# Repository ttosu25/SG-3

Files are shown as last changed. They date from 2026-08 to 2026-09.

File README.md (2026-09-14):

# Overview

Strain gauges produce very small differential voltage signals that encode information about mechanical strain. Precise and accurate measurement requires careful analogue signal conditioning before digitisation, followed by digital signal processing to extract the desired measurement. This project explores the design of a complete measurement device, from sensor excitation and analogue front-end conditioning through to digital acquisition, processing, and display output.

# System Block Diagram
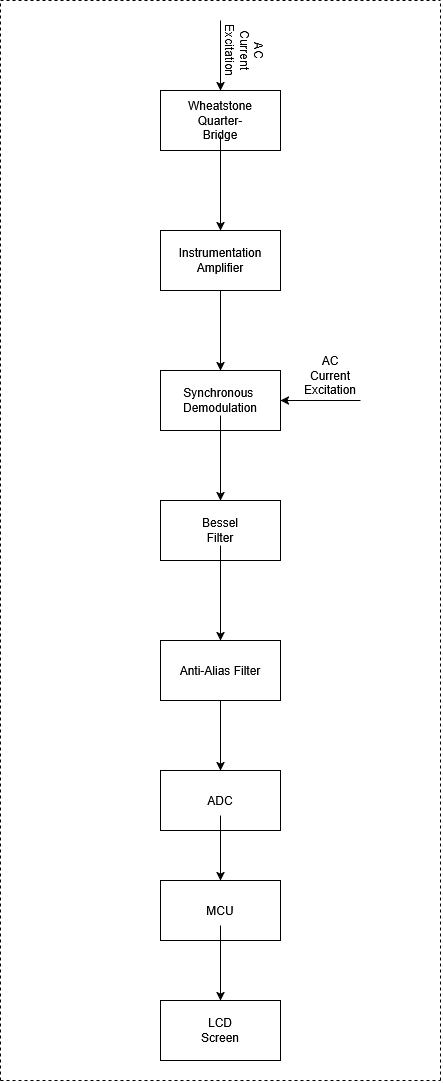
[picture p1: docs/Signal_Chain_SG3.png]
System Block Diagram


# Key Design Features

## AC Current Excitation
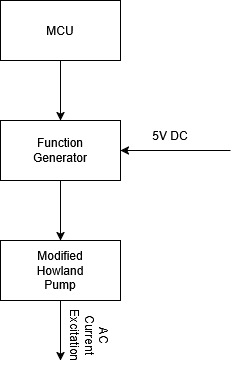
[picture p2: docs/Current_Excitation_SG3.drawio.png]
AC Current Excitation Block Diagram
  

Current-driven AC excitation: Current excitation improves the linearity between applied strain and differential bridge output. Using AC rather than DC excitation reduces measurement offset and drift, mitigates low frequency (1/f) noise, and suppresses parasitic thermoelectric effects.
  
## Bessel Filtering
The Bessel response was selected for its absence of overshoot and steeper amplitude roll-off compared with the Butterworth response. The filter also exhibits minimal passband variation and a simulated settling time of 7 ms, which is significantly shorter than the latency introduced by the sigma-delta ADC's digital filtering.

## Oversampled Sigma Delta ADC
Sigma-Delta converters contain integrated features such as digital filters that minimise the effect of extrinsic and intrinsic noise sources such as alias signal noise, 50/60hz power noise, RF noise pick up and clock jitter. The Oversampling nature of Sigma-Delta converts also distributes noise over a wider range of frequencies which reduces the effect of quantisation noise.

# Schematic
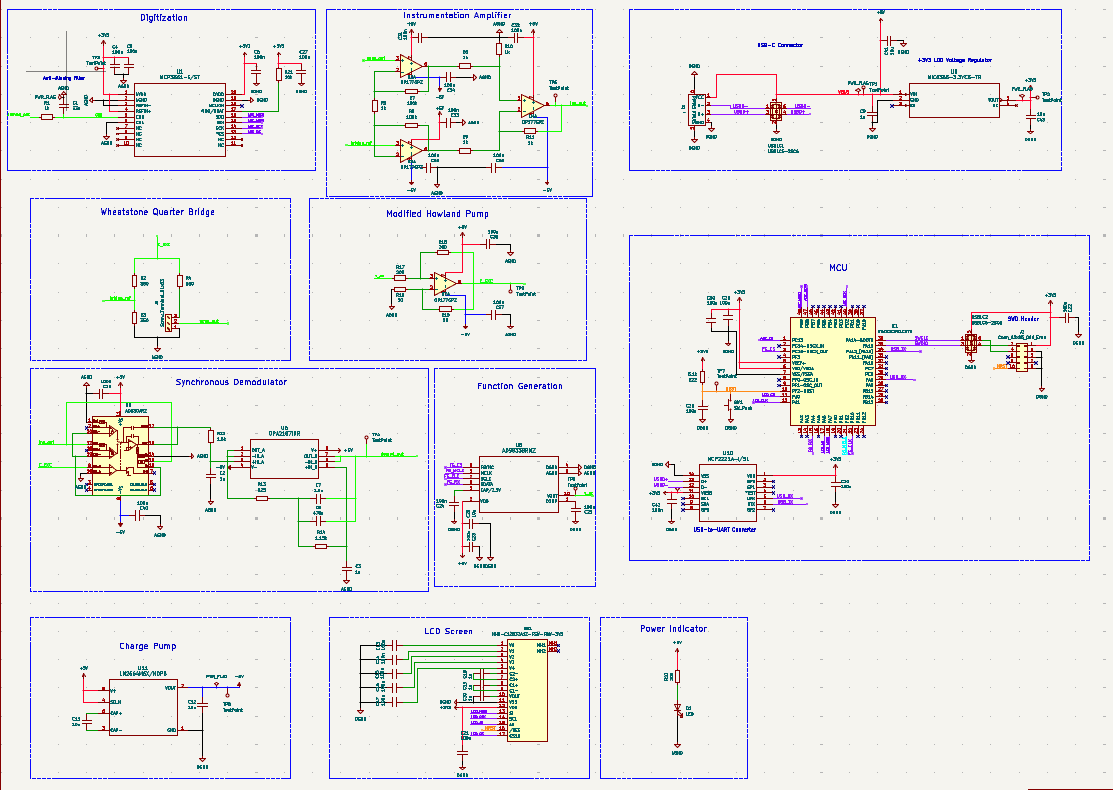
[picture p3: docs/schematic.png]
Hardware Schematic


# PCB Layout and Tracing
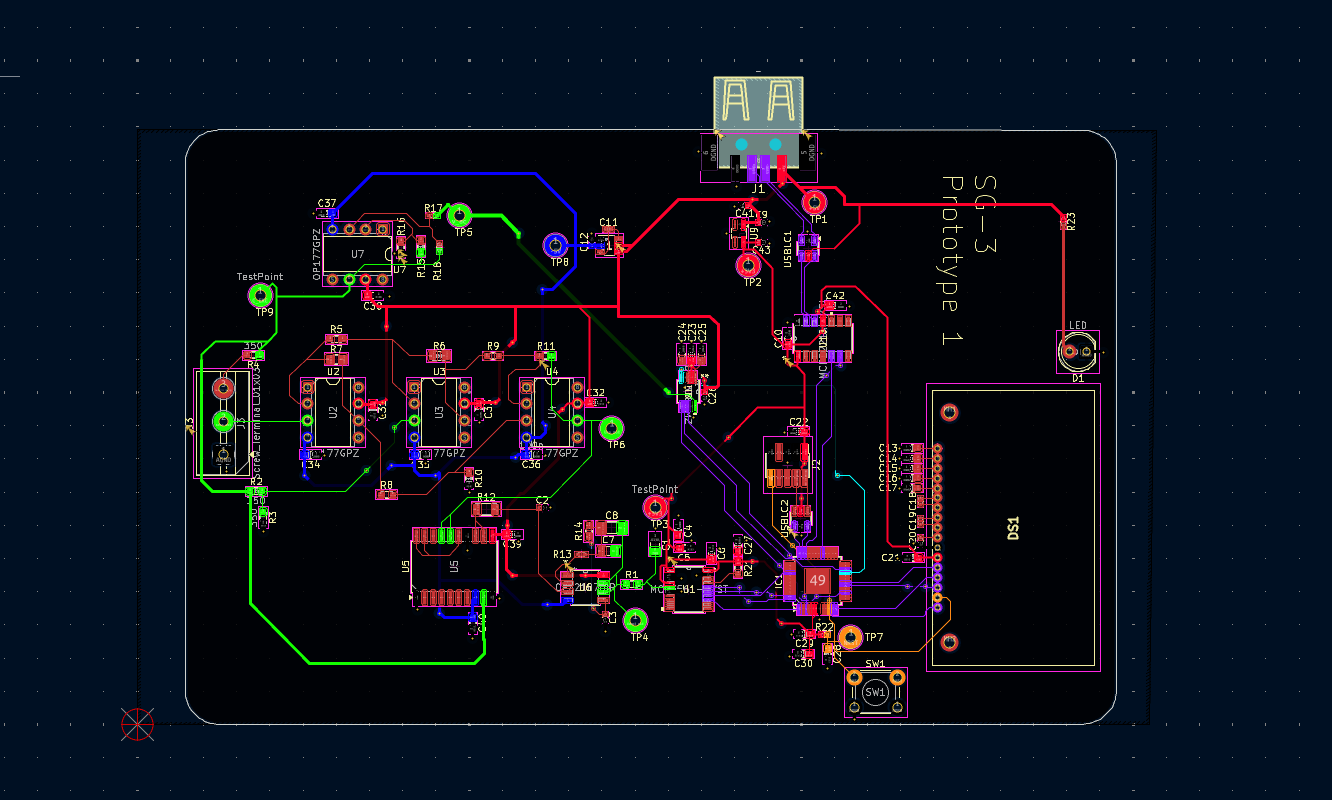
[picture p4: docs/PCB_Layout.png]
PCB Layout


# 3D model view
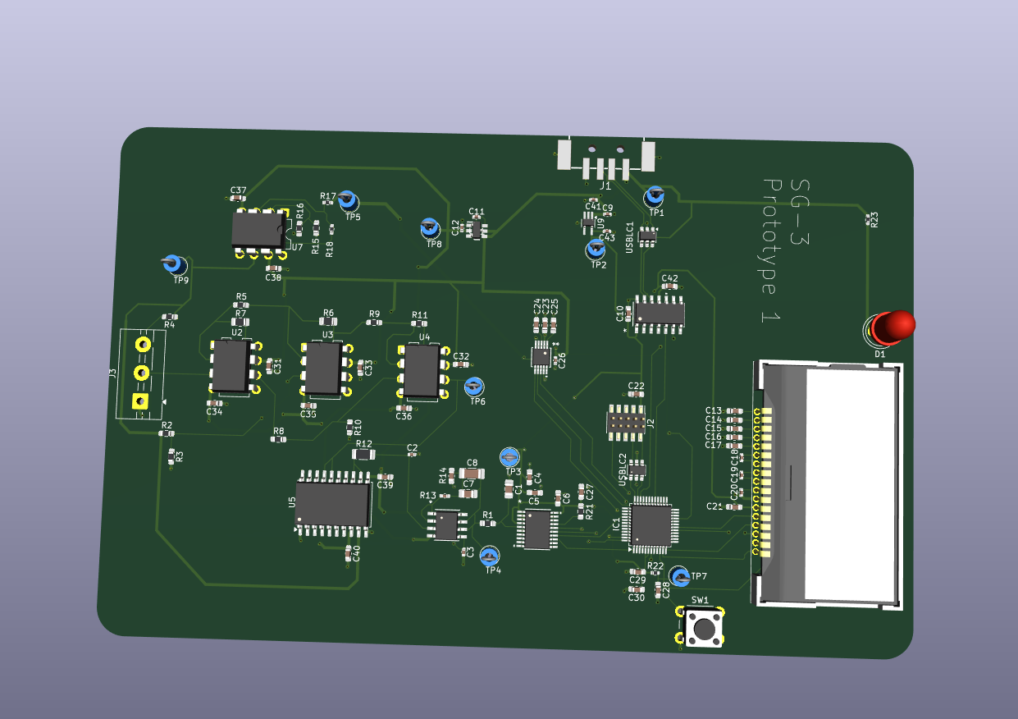
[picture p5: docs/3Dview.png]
3D model view


# Repository Structure

hardware/ — Contains the schematics, PCB layout files, Gerber files, MCU pin assignment, and hardware revisions.

tr/ — Contains technical research and supporting analysis, including datasheets, application notes, initial problem-space exploration, and SPICE simulations with FFT analysis.

docs/ — Contains the project specification, design documentation, and system diagrams.

firmware/ — Contains the programs running on the MCU for the embedded application.

Logbook entries not available.

# Status
Prototyping Stage, PCB fabricated.

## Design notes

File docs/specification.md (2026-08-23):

# Strain Gauge Measurement System (Load Sensing Node)

## 1. Project Overview

Design and implement a low-cost strain measurement system for monitoring mechanical strain on a loaded beam. The system will acquire strain data from a resistive strain gauge, condition the signal, and provide a digital output for logging and analysis.

The design should be suitable for laboratory testing and demonstrate correct analog signal conditioning principles.

## 2. Functional Requirements

The system shall:

Measure strain using a bonded resistive strain gauge
Convert strain into a usable electrical signal via a Wheatstone bridge
Condition the signal using analogue circuitry
Output a digital representation of strain for logging or display
Operate continuously under static or slowly varying loads

## 3. Sensor Requirements
Strain gauge nominal resistance: 350 Ω
Gauge factor: 2.0 ± 5%
Mounting: quarter-bridge configuration (unless justified otherwise in design)
Maximum strain range: 0 to 1200 µε
Assume linear elastic behaviour of the test specimen

## 4. Electrical Requirements

Minimum resolution target: ≤ 5 µε
Total system non-linearity: < 1% full scale

## 5. Data Conversion

ADC resolution: ≥ 12-bit
Sampling rate: ≥ 50 Hz

## 6. Mechanical Assumptions
Strain gauge is correctly bonded to a uniform metallic beam
Beam behaves within elastic region (Hooke’s law valid)
Temperature is approximately constant (20–25°C), but drift effects should be discussed

## 7. Environmental Constraints
Laboratory environment (non-industrial)
No significant vibration or EMI shielding provided
Cable lengths: up to 1 m between sensor and conditioning circuit

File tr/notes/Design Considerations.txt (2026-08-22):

The system seems to have a data flow structure as follows:

Force -> Foil Grid -> Piezoelectric signals -> Instrumentation Amplifier -> Signal Conditioning -> Digitization -> strain calculation/data logging system.

A reference voltage must be supplied to the instrumentation amplifier because strain gauges
can increase and decrease in resistance which produces a positive and negative differential bridge voltage. 

The reference voltage should be half the power supply voltage. A reference voltage at mid supply biases the output voltage of instrumentation amplifier to allow differential measurements in the positive and negative direction.

## References

Single-Supply Strain Gauge in a Bridge Configuration
Reference Design - TDI

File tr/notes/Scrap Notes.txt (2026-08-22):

## Overview

There are different implementations of a strain gauge using mechanical and optical methods. 
The type of strain-gauge to be designed and studied is the electrical resistance strain gauge.

These gauges are strongly bonded to the material being measured and they work on the principle that the electrical resistance of a conductive metal changes as it deforms. As the metal compresses and extends so does the gauge. By measuring the electrical signals generated due to these deformations, the object's change in length can be estimated and thus its strain on the surface.

## Construction

Consists of:
 - Conducting foil grid
 - Insulating plastic film
 - soldered tabs
 - alignment ends

The physical length of the grid is selected depending on the application. The shorter the length of the grid the more accurately the approximation of strain. However, a strain value averaged over a longer distance might be more meaningful for measuring strain of composite materials.

Different materials change resistance differently under the same unit strain. Materials that change resistance more for the same unit strain produce higher sensitivity strain gauges.

The sensitivity as a strain gauge is quantified by a parameter called the gauge factor K which is the ratio of the relative change in resistance to the strain.

Most general purpose strain gauges use foil grids made of constantan. It's K is moderate (2). Notably because of its performance with temperature. It's gauge factor varies very little between -50 to 150 degrees Celsius. Strain gauges tend to be used to measure small strains usually in the order of 1 to 1000 micro strain.

## Measurement

The principle circuit for the measurement of electrical signals in a strain gauge is a Wheatstone bridge. Its purpose is to determine the electric resistance of the strain gauge before and after a load has been applied.

### Basic Construction

- Four resistors arranged in a diamond shape
- A galvanometer splitting resistor network
- Voltage supply

## Temperature compensation

When materials experience temperature changes they expand and contract by a certain amount depending on their coefficient of thermal expansion (CTE) . The strain gauge material and the material being tested will have different CTEs so they will try to expand my different amounts.

This causes differential thermal expansion that gets added to strain different from what we are trying to measure.

### Compensation methods:

- active componesation
- self compensation

## Limitations

- Only measure normal strain in single direction.

## References
https://www.youtube.com/watch?v=CRa9djnZRu0

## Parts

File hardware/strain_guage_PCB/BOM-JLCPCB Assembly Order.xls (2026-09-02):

JLCPCB BOM Tool - BOM Matching
BOM name：BOM-JLCPCB Assembly Order.xlsx |  |  | Download Time：2026-09-02 18:14:43 |  |  |  | * Our matching results are updated in real-time, but stock and prices may change. If it's been over 24 hours, please re-match before placing your order.
PCB Assembled Qty：5 |  |  | Est. Total Price：240.3413
Your BOM |  |  |  | Matched Parts |  |  |  |  |  |  | Order Information
Designator | Comment | Footprint | JLCPCB Part # | Matches | Part # | Manufacturer | Footprint | Description | Category | Warning | JLCPCB Part # | Product link | Lib Type | Qty | Source | Total Price ($)
C1 | 33n | Capacitor_SMD:C_0805_2012Metric_Pad1.18x1.45mm_HandSolder |  | Select by Customer | C0805C333F3GACTU | KEMET | 0805 | 0805 Multilayer Ceramic Capacitors MLCC - SMD/SMT ROHS |  |  | C28364709 | https://jlcpcb.com/partdetail/KEMET-C0805C333F3GACTU/C28364709 | Extended | 2 | 2 JLCPCB | 4.1946
C4,C5,C6,C10,C13,C14,C15,C16,C17,C21,C22,C23,C24,C25,C27,C28,C29,C30,C31,C32,C33,C34,C35,C36,C37,C38,C39,C40,C42 | 100n | Capacitor_SMD:C_0603_1608Metric_Pad1.08x0.95mm_HandSolder |  | Select by System | CC0603KRX7R9BB104 | YAGEO | 0603 | 100nF 50V X7R ±10% 0603 Multilayer Ceramic Capacitors MLCC - SMD/SMT ROHS | Multilayer Ceramic Capacitors MLCC - SMD/SMT |  | C14663 | https://jlcpcb.com/partdetail/YAGEO-CC0603KRX7R9BB104/C14663 | Basic | 58 | 58 JLCPCB | 0.8004
C7 | 1.5u | Capacitor_SMD:C_0805_2012Metric_Pad1.18x1.45mm_HandSolder |  | Select by System | C2012X7R1E155KT000N | TDK | 0805 | 1.5uF 25V X7R ±10% 0805 Multilayer Ceramic Capacitors MLCC - SMD/SMT ROHS | Multilayer Ceramic Capacitors MLCC - SMD/SMT |  | C338028 | https://jlcpcb.com/partdetail/TDK-C2012X7R1E155KT000N/C338028 | Extended | 5 | 5 JLCPCB | 0.6295
C8 | 470n | Capacitor_SMD:C_1206_3216Metric_Pad1.33x1.80mm_HandSolder |  | Select by System | 1206B474K101NT | FH (Guangdong Fenghua Advanced Tech) | 1206 | 100V 470nF X7R ±10% 1206 Multilayer Ceramic Capacitors MLCC - SMD/SMT ROHS | Multilayer Ceramic Capacitors MLCC - SMD/SMT |  | C507059 | https://jlcpcb.com/partdetail/520999-1206B474K101NT/C507059 | Extended | 15 | 15 JLCPCB | 1.089
C11,C12,C26,C41,C43 | 10u | Capacitor_SMD:C_0402_1005Metric |  | Select by System | CL05A106MQ5NUNC | Samsung Electro-Mechanics | 0402 | 10uF 6.3V X5R ±20% 0402 Multilayer Ceramic Capacitors MLCC - SMD/SMT ROHS | Multilayer Ceramic Capacitors MLCC - SMD/SMT |  | C15525 | https://jlcpcb.com/partdetail/16204-CL05A106MQ5NUNC/C15525 | Basic | 10 | 10 JLCPCB | 0.255
D1 | LED | LED_THT:LED_D5.0mm |  | Select by Customer | 333-2SURD/S530-A3 | Everlight Elec | 插件,D=5mm | -40℃~+85℃ 200mcd 20mA 2V 30° 5mm round lamp head 624nm 632nm Red Red Lens 插件,D=5mm LED Indication - Discrete ROHS | LED Indication - Discrete |  | C87271 | https://jlcpcb.com/partdetail/EverlightElec-333_2SURD_S530A3/C87271 | Extended | 7 | 7 JLCPCB | 0.266
J1 | USB_C_Receptacle_USB2.0_16P | USBC:UJ20CHGMSMT4BP16TR |  | Select by Customer | BX-TYPE-A-MWT4P | Bossie | SMD | -20℃~+70℃ 1 1.5A 13.5mm 30V 4P 5,000 cycles Female Surface Mount, Right Angle Type-A USB 2.0 White SMD USB Connectors ROHS | USB Connectors |  | C18077687 | https://jlcpcb.com/partdetail/Bossie-BX_TYPE_AMWT4P/C18077687 | Extended | 2 | 2 JLCPCB | 0.2414
J2 | Conn_02x05_Odd_Even | Connector_PinHeader_1.27mm:PinHeader_2x05_P1.27mm_Vertical_SMD |  | Select by Customer | FTSH-105-01-L-DV-K | Samtec | SMD,P=1.27mm | -55℃~+125℃ 1.27mm 10P 2 2x5P 3.05mm 3.4A Black Gold Phosphor bronze Pin Header Surface Mount,Vertical SMD,P=1.27mm Pin Headers ROHS | Pin Headers |  | C5155080 | https://jlcpcb.com/partdetail/Samtec-FTSH_105_01_L_DVK/C5155080 | Extended | 2 | 2 JLCPCB | 2.858
J3 | Screw_Terminal_01x03 | TerminalBlock_MaiXu_MX126-5.0-03P_1x03_P5.00mm |  | Select by Customer | WJ128V-5.0-03P-14-00A | Ningbo Kangnex Elec | 插件,P=5mm | -40℃~+105℃ 1 12~22 1x3P 2.5 20A 250V 3 3P 5mm Green Through Hole 插件,P=5mm Screw Terminal Blocks ROHS | Screw Terminal Blocks |  | C8270 | https://jlcpcb.com/partdetail/8762-WJ128V_5_0_03P_1400A/C8270 | Extended | 2 | 2 JLCPCB | 0.415
R1,R5,R8,R9,R10,R11 | 1k | Resistor_SMD:R_0603_1608Metric_Pad0.98x0.95mm_HandSolder |  | Select by System | 0603WAF1001T5E | UNI-ROYAL(Uniroyal Elec) | 0603 | -55℃~+155℃ 100mW 1kΩ 75V Thick Film Resistor ±1% ±100ppm/℃ 0603 Chip Resistor - Surface Mount ROHS | Chip Resistor - Surface Mount |  | C21190 | https://jlcpcb.com/partdetail/21904-0603WAF1001T5E/C21190 | Basic | 12 | 12 JLCPCB | 0.0396
R2,R3,R4 | 350 | Resistor_SMD:R_0603_1608Metric_Pad0.98x0.95mm_HandSolder |  | Select by System | ZLLS350TA | Diodes Incorporated | SOD-523 | 1 Independent 1V@275mA 380mA 40V 4uA@30V 6A SOD-523 Schottky Diodes ROHS | Schottky Diodes |  | C139441 | https://jlcpcb.com/partdetail/DiodesIncorporated-ZLLS350TA/C139441 | Extended | 8 | 8 JLCPCB | 2.336
R6,R7 | 100k | Resistor_SMD:R_0805_2012Metric_Pad1.20x1.40mm_HandSolder |  | Select by System | 0805W8F1003T5E | UNI-ROYAL(Uniroyal Elec) | 0805 | -55℃~+155℃ 100kΩ 125mW 150V Thick Film Resistor ±1% ±100ppm/℃ 0805 Chip Resistor - Surface Mount ROHS | Chip Resistor - Surface Mount |  | C149504 | https://jlcpcb.com/partdetail/160838-0805W8F1003T5E/C149504 | Basic | 4 | 4 JLCPCB | 0.0236
R12 | 1.5k | Resistor_SMD:R_1206_3216Metric |  | Select by System | FRC1206J152 TS | FOJAN | 1206 | -55℃~+155℃ 1.5kΩ 200V 250mW Thick Film Resistor ±100ppm/℃ ±5% 1206 Chip Resistor - Surface Mount ROHS | Chip Resistor - Surface Mount |  | C2907413 | https://jlcpcb.com/partdetail/FOJAN-FRC1206J152TS/C2907413 | Extended | 15 | 15 JLCPCB | 0.0735
R14 | 1.15k | Capacitor_SMD:C_0603_1608Metric_Pad1.08x0.95mm_HandSolder |  | Select by System | FRC0603F1151TS | FOJAN | 0603 | -55℃~+155℃ 1.15kΩ 100mW 75V Thick Film Resistor ±1% ±100ppm/℃ 0603 Chip Resistor - Surface Mount ROHS | Chip Resistor - Surface Mount |  | C2998059 | https://jlcpcb.com/partdetail/FOJAN-FRC0603F1151TS/C2998059 | Extended | 20 | 20 JLCPCB | 0.044
R15,R16 | 50 | Resistor_SMD:R_0603_1608Metric_Pad0.98x0.95mm_HandSolder |  | Select by System | RT0603BRE0750RL | YAGEO | 0603 | -55℃~+155℃ 100mW 50Ω 75V Thin Film Resistor ±0.1% ±50ppm/℃ 0603 Chip Resistor - Surface Mount ROHS | Chip Resistor - Surface Mount |  | C849792 | https://jlcpcb.com/partdetail/YAGEO-RT0603BRE0750RL/C849792 | Extended | 20 | 20 JLCPCB | 0.568
R17,R18,R23 | 200 | Resistor_SMD:R_0402_1005Metric_Pad0.72x0.64mm_HandSolder |  | Select by Customer | RCT02200RFLF | HKR(Hong Kong Resistors) | 0402 | -55℃~+155℃ 200Ω 50V 62.5mW Thick Film Resistor ±1% ±200ppm/℃ 0402 Chip Resistor - Surface Mount ROHS | Chip Resistor - Surface Mount |  | C173573 | https://jlcpcb.com/partdetail/184963-RCT02200RFLF/C173573 | Extended | 20 | 20 JLCPCB | 0.014
R21 | 10k | Resistor_SMD:R_0603_1608Metric_Pad0.98x0.95mm_HandSolder |  | Select by System | 0603WAF1002T5E | UNI-ROYAL(Uniroyal Elec) | 0603 | -55℃~+155℃ 100mW 10kΩ 75V Thick Film Resistor ±1% ±100ppm/℃ 0603 Chip Resistor - Surface Mount ROHS | Chip Resistor - Surface Mount |  | C25804 | https://jlcpcb.com/partdetail/26547-0603WAF1002T5E/C25804 | Basic | 2 | 2 JLCPCB | 0.005
R22 | 5.1k | Resistor_SMD:R_0201_0603Metric |  | Select by Customer | RCA025K1JLF | HKR(Hong Kong Resistors) | 0402 | -55℃~+155℃ 5.1kΩ 50V 62.5mW Thick Film Resistor ±200ppm/℃ ±5% 0402 Chip Resistor - Surface Mount ROHS |  |  | C22356228 | https://jlcpcb.com/partdetail/23789672-RCA025K1JLF/C22356228 | Extended | 20 | 20 JLCPCB | 0.018
SW1 | SW_Push | Button_Switch_THT:SW_PUSH_6mm |  | Select by Customer | K2-6639DP-B4SW-04 | Korean Hroparts Elec | 插件-4P,6x6mm | -25℃~+85℃ 1,000,000 cycles 12V 2.5N 4.5mm 50mA 6mm 6mm Round Button SPST Through Hole 插件-4P,6x6mm Tactile Switches ROHS | Tactile Switches |  | C83205 | https://jlcpcb.com/partdetail/Korean_HropartsElec-K2_6639DP_B4SW04/C83205 | Extended | 3 | 3 JLCPCB | 0.1374
U1 | MCP3561-E/ST | TSSOP20_ST_MCH |  | Select by System | MCP3561-E/ST | Microchip Tech | TSSOP-20 | -40℃~+125℃ 1 107.2dB 153.6kHz 153.6kHz 1MHz~20MHz、3.3MHz~6.6MHz 2.7V~3.6V 24 Built-in External、Built-in SPI Sigma-Delta Support Yes TSSOP-20 Analog to Digital Converters (ADC) ROHS | Analog To Digital Converters (ADC) |  | C1012815 | https://jlcpcb.com/partdetail/MicrochipTech-MCP3561_EST/C1012815 | Extended | 2 | 2 JLCPCB | 12.4438
U2,U3,U4,U7 | OP177GPZ | Package_SO:SOIC-8_5.3x5.3mm_P1.27mm |  | Select by System | OP177GPZ | Analog Devices | PDIP-8 | -40℃~+85℃ 0.3V/us 1 1.2nA 1.2uV/℃ 1.6mA 140dB 2.8nA 600kHz 60uV PDIP-8 Precision Op Amps ROHS | Precision Op Amps |  | C96524 | https://jlcpcb.com/partdetail/AnalogDevices-OP177GPZ/C96524 | Extended | 8 | 8 JLCPCB | 54.0184
U5 | AD630ARZ | Package_SO:SOIC-20W_7.5x12.8mm_P1.27mm |  | Select by System | AD630ARZ | Analog Devices | SOIC-20-300mil | -16.5V~-5V、5V~16.5V 2MHz SOIC-20-300mil Special Purpose Amplifiers ROHS | RFID ICs |  | C495335 | https://jlcpcb.com/partdetail/AnalogDevices-AD630ARZ/C495335 | Extended | 2 | 2 JLCPCB | 107.6344
U6 | OPA2187IDR | D8_TEX |  | Select by System | OPA2187IDR | Texas Instruments | SOIC-8 | -18V~-2.25V、2.25V~18V -40℃~+125℃ 0.2V/us 100pA 100pA 100uA 140dB 1nV/℃ 1uV 2 20nV/√Hz@1kHz 30mA 36V 550kHz EMI filtering/RF suppression、Zero drift / auto-zero、Reverse-phase input protection Rail-to-rail output SOIC-8 Precision Op Amps ROHS | Precision Op Amps |  | C2058572 | https://jlcpcb.com/partdetail/TexasInstruments-OPA2187IDR/C2058572 | Extended | 2 | 2 JLCPCB | 4.8174
U8 | AD9833BRMZ | RM_10_ADI |  | Select by System | AD9833BRMZ | Analog Devices | MSOP-10 | -40℃~+105℃ 10 12.5MHz 1LSB 2.3V~5.5V 25MHz 28 60dB Integrated modulator、Phase continuous switching、Low-power mode、Enable/shutdown function SPI Voltage MSOP-10 Direct Digital Synthesis (DDS) ROHS | Direct Digital Synthesis (DDS) |  | C1519069 | https://jlcpcb.com/partdetail/AnalogDevices-AD9833BRMZ/C1519069 | Extended | 2 | 2 JLCPCB | 32.3326
U9 | MIC5365-3.3YC5-TR | Package_TO_SOT_SMD:TSOT-23-5 |  | Select by System | MIC5365-3.3YC5-TR | Microchip Tech | SC-70-5 | -40℃~+125℃ 1 150mA 200uVrms 3.3V 310mV@(150mA) 39uA 5.5V 65dB@(10kHz)、80dB@(1kHz) Fixed Over Current Protection、Over Temperature Protection、Enable Positive SC-70-5 Voltage Regulators - Linear, Low Drop Out (LDO) Regulators ROHS | Voltage Regulators - Linear, Low Drop Out (LDO) Regulators |  | C73103 | https://jlcpcb.com/partdetail/MicrochipTech-MIC5365_3_3YC5TR/C73103 | Extended | 5 | 5 JLCPCB | 1.6115
U10 | MCP2221A-I/SL | SOIC14_SL_MCH |  | Select by System | MCP2221A-I/SL | Microchip Tech | SOIC-14 | -40℃~+85℃ 13mA 3V~5.5V 46uA USB 2.0 USB to UART、USB to I2C SOIC-14 USB Converters ROHS | USB Converters |  | C640876 | https://jlcpcb.com/partdetail/MicrochipTech-MCP2221A_ISL/C640876 | Extended | 2 | 2 JLCPCB | 12.3596
U11 | LM2664M6X/NOPB | DBV0006A_N |  | Select by System | LM2664M6X/NOPB | Texas Instruments | SOT-23-6 | -40℃~+85℃ -5.5V~-1.8V 1.8V~5.5V 12Ω 220uA 40mA 80kHz 91% Inverted Not supported SOT-23-6 Charge Pumps ROHS | Charge Pumps |  | C108573 | https://jlcpcb.com/partdetail/TexasInstruments-LM2664M6XNOPB/C108573 | Extended | 2 | 2 JLCPCB | 0.7596
USBLC1,USBLC2 | USBLC6-2SC6 | Package_TO_SOT_SMD:SOT-23-6 |  | Select by System | USBLC6-2SC6 | TECH PUBLIC | SOT-23-6 | -55℃~+125℃ 0.35pF 12V 150W 2 5V 6A 6V 80nA ESD IEC 61000-4-2、IEC 61000-4-5、IEC 61000-4-4 Unidirectional SOT-23-6 ESD and Surge Protection (TVS/ESD) ROHS | ESD And Surge Protection (TVS/ESD) |  | C2827654 | https://jlcpcb.com/partdetail/TECHPUBLIC-USBLC62SC6/C2827654 | Extended | 8 | 8 JLCPCB | 0.356

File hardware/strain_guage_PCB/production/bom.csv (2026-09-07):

Designator | Footprint | Quantity | Value | LCSC Part #
C1 | 0805 | 1 | 33n
C10, C13, C14, C15, C16, C17, C21, C22, C23, C24, C25, C27, C28, C29, C30, C31, C32, C33, C34, C35, C36, C37, C38, C39, C4, C40, C42, C5, C6 | 0603 | 29 | 100n
C11, C12, C26, C41, C43 | 0402 | 5 | 10u
C18, C19, C2, C20, C3, C9 | 0402 | 6 | 1u
C7 | 0805 | 1 | 1.5u
C8 | 1206 | 1 | 470n
D1 | LED_D5.0mm | 1 | LED
DS1 | NHDC12832A1ZFSWFBW3V3 | 1 | NHD-C12832A1Z-FSW-FBW-3V3
IC1 | LQFP-48-1EP_7x7mm_P0.5mm_EP3.6x3.6mm | 1 | STM32C091CBT6
J1 | USB-A-SMD_BX-TYPE-A-MWT4P | 1 | ~
J2 | PinHeader_2x05_P1.27mm_Vertical_SMD | 1 | Conn_02x05_Odd_Even
J3 | TerminalBlock_MaiXu_MX126-5.0-03P_1x03_P5.00mm | 1 | Screw_Terminal_01x03
R1, R10, R11, R5, R8, R9 | 0603 | 6 | 1k
R12 | 1206 | 1 | 1.5k
R13 | 0402 | 1 | 825
R14 | 0603 | 1 | 1.15k
R15, R16 | 0603 | 2 | 50
R17, R18, R23 | 0402 | 3 | 200
R2, R3, R4 | 0603 | 3 | 350
R21 | 0603 | 1 | 10k
R22 | 0402 | 1 | 5.1k
R6, R7 | 0805 | 2 | 100k
SW1 | SW_PUSH_6mm | 1 | SW_Push
TP1, TP2, TP3, TP4, TP5, TP6, TP7, TP8, TP9 | TestPoint_Loop_D2.54mm_Drill1.5mm_Beaded | 9 | TestPoint
U1 | TSSOP20_ST_MCH | 1 | MCP3561-E/ST
U10 | SOIC14_SL_MCH | 1 | MCP2221A-I/SL
U11 | DBV0006A_N | 1 | LM2664M6X/NOPB
U2, U3, U4, U7 | DIP794W56P254L959H533Q8N | 4 | OP177GPZ
U5 | SOIC-20W_7.5x12.8mm_P1.27mm | 1 | AD630ARZ
U6 | D8_TEX | 1 | OPA2187IDR
U8 | RM_10_ADI | 1 | AD9833BRMZ
U9 | SOT-353_SC-70-5_Handsoldering | 1 | MIC5365-3.3YC5-TR
USBLC1, USBLC2 | SOT-23-6 | 2 | USBLC6-2SC6

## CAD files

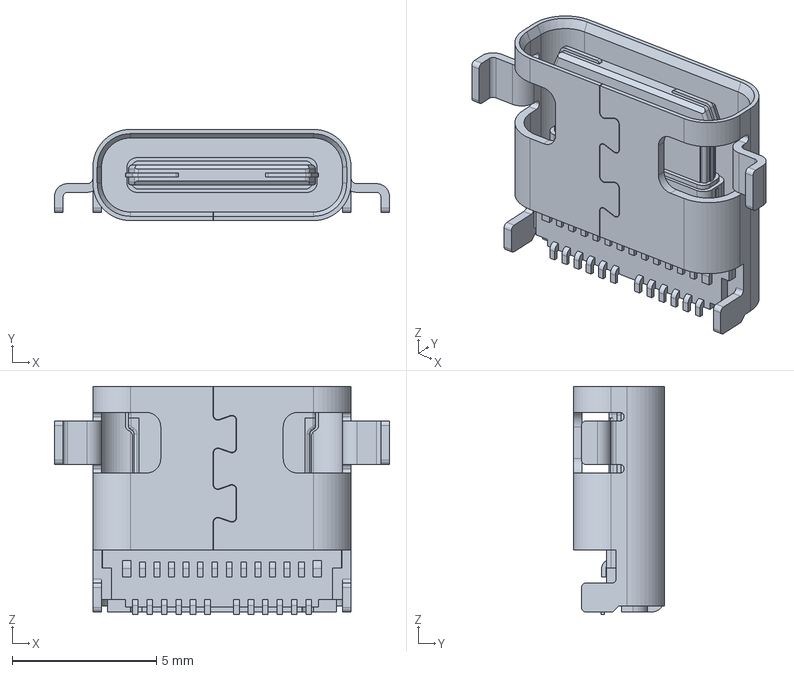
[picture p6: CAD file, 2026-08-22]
hardware/strain_guage_PCB/ul_1054550101/1054550101.stp
11.6 x 3.16 x 7.90 mm

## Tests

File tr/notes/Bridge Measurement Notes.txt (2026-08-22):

## Bridge Configurations

For a Quarter Bridge, current excitation reduces non-linearity error by approximately half.

For a half bridge, the differential measured voltage is two times larger for a given excitation voltage. Thus the configuration doubles the dynamic range compared to the quarter bridge resulting in better ADC measurement

For a half bridge, current excitation completely removes non-linearity error

For a full bridge the sensitivity is two times greater than both two-active element bridge configurations and four times greater than the single active element bridge. Also this configuration inherently has no non-linearity.

## Bridge Connections

A benefit of radiometric measurement is that the measurement is relatively invariant to changes in reference voltage. The output of the ADC code is independent of th eexact value of VREF or excitation voltage.

For four wire bridges, the issue is that if the reference voltage leads are too long,
they can produce a parasitic resistance which increases the percentage error on the measurement of the reference voltage.

## Relevant Definitions
non-linearity error: the deviation of an actual output curve from an ideal straight line in a measurement or control system

A ratiometric measurement evaluates a target signal by comparing it proportionally to a known reference signal, rather than measuring it as an absolute value.

A Kelvin connection (or four-wire sensing) is a wiring method used to accurately measure voltage drops across a current sense resistor by eliminating the resistance of the copper traces and solder joints

Sense wires, measure voltage without loading the circuit.

Output-common-mode voltage: The average voltage between the two outputs of a differential circuit or amplifier relative to a common reference.

## References
A Basic Guide to Bridge Measurements -TI

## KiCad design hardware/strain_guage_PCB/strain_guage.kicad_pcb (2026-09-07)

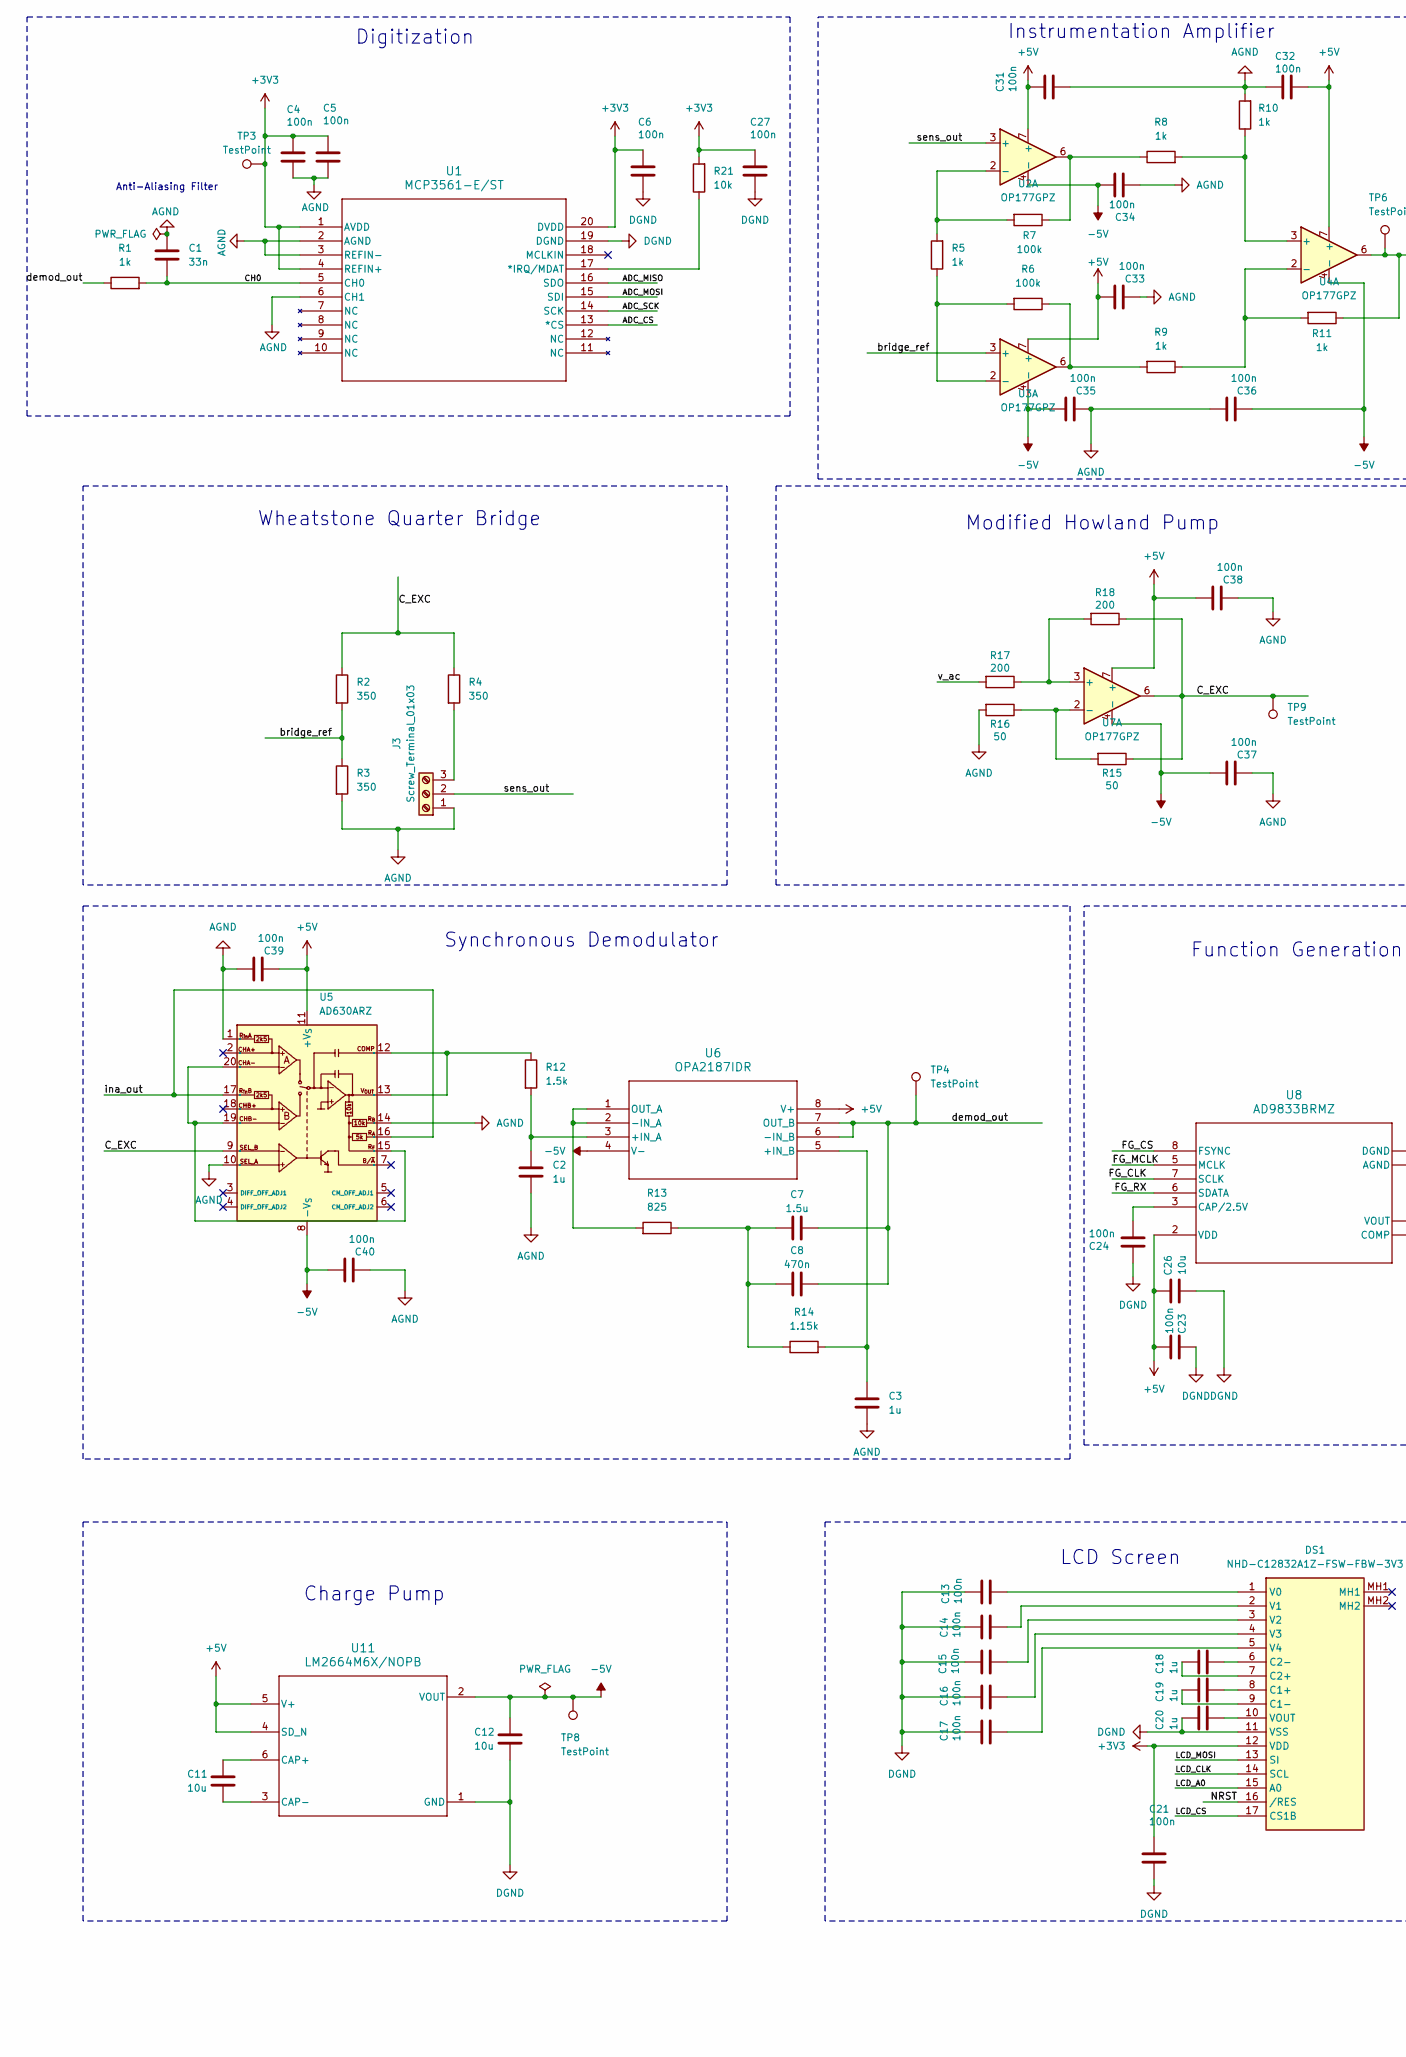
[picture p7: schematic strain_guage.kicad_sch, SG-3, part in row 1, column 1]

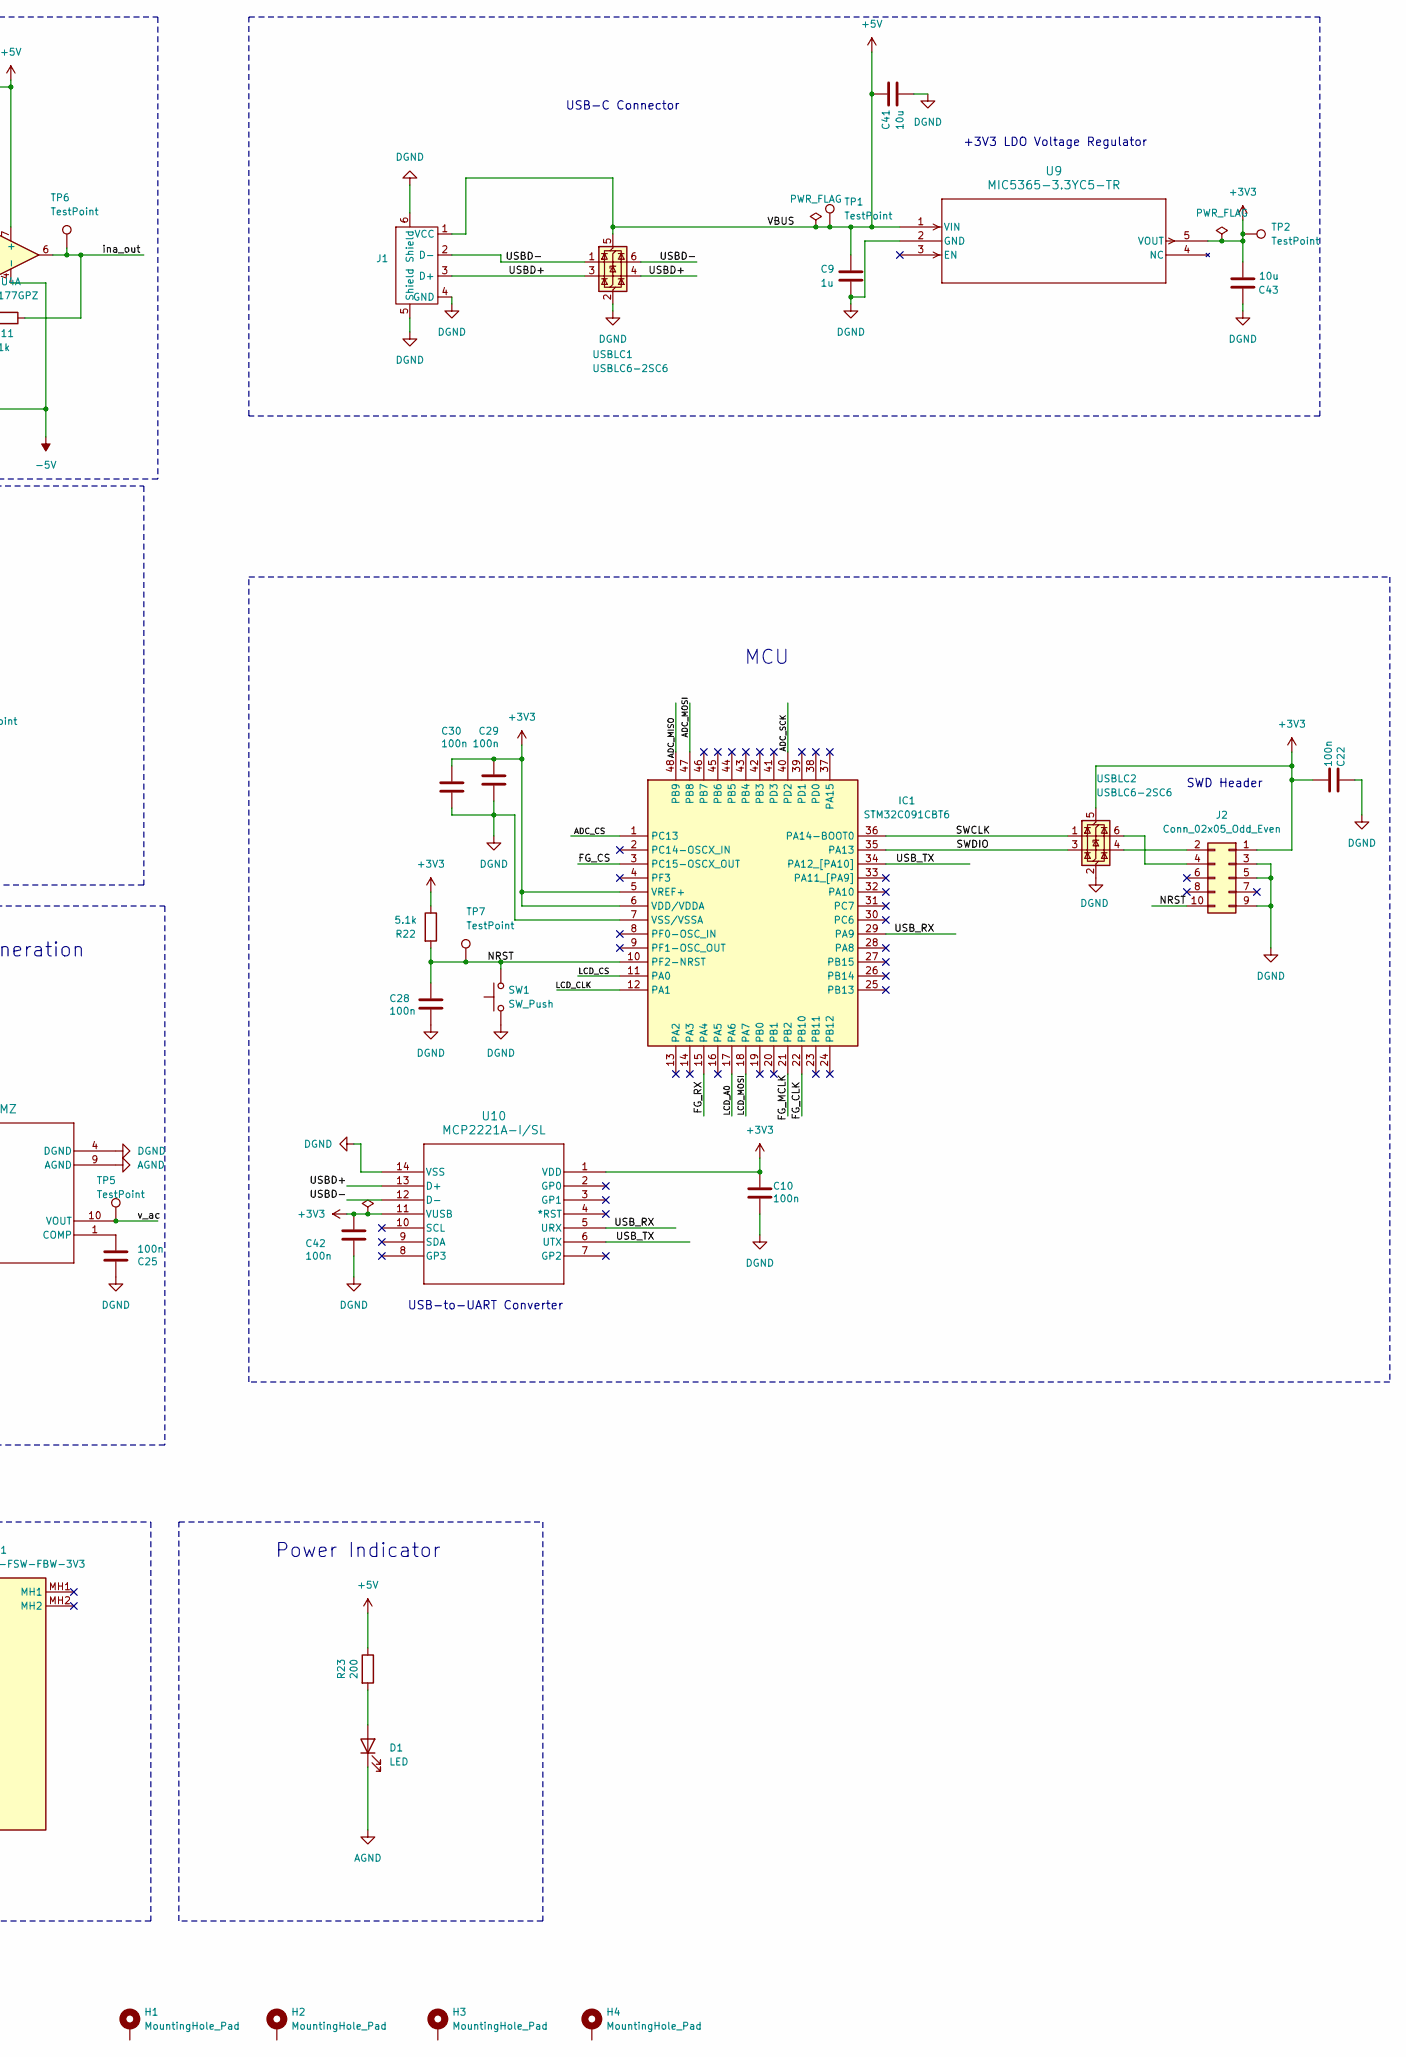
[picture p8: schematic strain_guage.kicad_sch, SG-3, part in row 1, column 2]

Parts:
C1: 33n; C_0805_2012Metric_Pad1.18x1.45mm_HandSolder
C2, C3, C9, C18, C19, C20: 1u; C_0402_1005Metric
C4, C5, C6, C10, C13, C14, C15, C16, C17, C21, C22, C23, C24, C25, C27, C28, C29, C30, C31, C32, C33, C34, C35, C36, C37, C38, C39, C40, C42: 100n; C_0603_1608Metric_Pad1.08x0.95mm_HandSolder
C7: 1.5u; C_0805_2012Metric_Pad1.18x1.45mm_HandSolder
C8: 470n; C_1206_3216Metric_Pad1.33x1.80mm_HandSolder
C11, C12, C26, C41, C43: 10u; C_0402_1005Metric
D1: LED; LED_D5.0mm
DS1: NHD-C12832A1Z-FSW-FBW-3V3; NHDC12832A1ZFSWFBW3V3; Manufacturer_Part_Number NHD-C12832A1Z-FSW-FBW-3V3; Mouser Part Number 763-C12832A1ZFSWFBW3
H1, H2, H3, H4: MountingHole_Pad; MountingHole_3.2mm_M3_ISO7380_Pad
IC1: STM32C091CBT6; LQFP-48-1EP_7x7mm_P0.5mm_EP3.6x3.6mm; Manufacturer_Part_Number STM32C091CBT6
J1: USB-A-SMD_BX-TYPE-A-MWT4P
J2: Conn_02x05_Odd_Even; PinHeader_2x05_P1.27mm_Vertical_SMD
J3: Screw_Terminal_01x03; TerminalBlock_MaiXu_MX126-5.0-03P_1x03_P5.00mm
R1, R5, R8, R9, R10, R11: 1k; R_0603_1608Metric_Pad0.98x0.95mm_HandSolder
R2, R3, R4: 350; R_0603_1608Metric_Pad0.98x0.95mm_HandSolder
R6, R7: 100k; R_0805_2012Metric_Pad1.20x1.40mm_HandSolder
R12: 1.5k; R_1206_3216Metric
R13: 825; C_0402_1005Metric_Pad0.74x0.62mm_HandSolder
R14: 1.15k; C_0603_1608Metric_Pad1.08x0.95mm_HandSolder
R15, R16: 50; R_0603_1608Metric_Pad0.98x0.95mm_HandSolder
R17, R18, R23: 200; R_0402_1005Metric_Pad0.72x0.64mm_HandSolder
R21: 10k; R_0603_1608Metric_Pad0.98x0.95mm_HandSolder
R22: 5.1k; R_0402_1005Metric
SW1: SW_Push; SW_PUSH_6mm
TP1, TP2, TP3, TP4, TP5, TP6, TP7, TP8, TP9: TestPoint; TestPoint_Loop_D2.54mm_Drill1.5mm_Beaded
U1: MCP3561-E/ST; TSSOP20_ST_MCH
U2, U3, U4, U7: OP177GPZ; DIP794W56P254L959H533Q8N
U5: AD630ARZ; SOIC-20W_7.5x12.8mm_P1.27mm
U6: OPA2187IDR; D8_TEX
U8: AD9833BRMZ; RM_10_ADI
U9: MIC5365-3.3YC5-TR; SOT-353_SC-70-5_Handsoldering
U10: MCP2221A-I/SL; SOIC14_SL_MCH
U11: LM2664M6X/NOPB; DBV0006A_N
USBLC1, USBLC2: USBLC6-2SC6; SOT-23-6

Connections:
+3V3: C4.1, C5.1, C6.1, C10.1, C21.1, C22.2, C27.1, C29.1, C30.1, C42.1, C43.2, DS1.12 (VDD), IC1.5 (VREF+), IC1.6 (VDD/VDDA), J2.1 (VTREF), R21.2, R22.1, TP2.1, TP3.1, U1.1 (AVDD), U1.4 (REFIN+), U1.20 (DVDD), U9.5 (VOUT), U10.1 (VDD), U10.11 (VUSB), USBLC2.5 (VBUS)
+5V: C9.1, C23.2, C26.1, C31.1, C32.1, C33.1, C38.1, C39.2, C41.1, J1.1 (VCC), R23.1, TP1.1, U2.7 (+), U3.7 (+), U4.7 (+), U5.11 (+V_{S}), U6.8 (V+), U7.7 (+), U8.2 (VDD), U9.1 (VIN), U11.4 (SD_N), U11.5 (V+), USBLC1.5 (VBUS)
-5V: C12.1, C34.1, C35.1, C36.2, C37.1, C40.1, TP8.1, U2.4 (-), U3.4 (-), U4.4 (-), U5.8 (-V_{S}), U6.4 (V-), U7.4 (-), U11.2 (VOUT)
/ADC_CS: IC1.1 (PC13), U1.13 (*CS)
/ADC_MISO: IC1.48 (PB9), U1.16 (SDO)
/ADC_MOSI: IC1.47 (PB8), U1.15 (SDI)
/ADC_SCK: IC1.40 (PD2), U1.14 (SCK)
/CH0: C1.2, R1.2, U1.5 (CH0)
/C_EXC: R2.1, R4.1, R15.1, R18.1, TP9.1, U5.9 (SEL_B), U7.6
/FG_CLK: IC1.22 (PB10), U8.7 (SCLK)
/FG_CS: IC1.3 (PC15-OSCX_OUT), U8.8 (FSYNC)
/FG_MCLK: IC1.21 (PB2), U8.5 (MCLK)
/FG_RX: IC1.15 (PA4), U8.6 (SDATA)
/LCD_A0: DS1.15 (A0), IC1.17 (PA6)
/LCD_CLK: DS1.14 (SCL), IC1.12 (PA1)
/LCD_CS: DS1.17 (CS1B), IC1.11 (PA0)
/LCD_MOSI: DS1.13 (SI), IC1.18 (PA7)
/NRST: C28.1, DS1.16 (/RES), IC1.10 (PF2-NRST), J2.10 (NRST), R22.2, SW1.2, TP7.1
/SWCLK: IC1.36 (PA14-BOOT0), USBLC2.1 (I/O1)
/SWDIO: IC1.35 (PA13), USBLC2.3 (I/O2)
/USBD+: J1.3 (D+), U10.13 (D+), USBLC1.3 (I/O2), USBLC1.4 (I/O2)
/USBD-: J1.2 (D-), U10.12 (D-), USBLC1.1 (I/O1), USBLC1.6 (I/O1)
/USB_RX: IC1.29 (PA9), U10.5 (URX)
/USB_TX: IC1.34 (PA12_[PA10]), U10.6 (UTX)
/bridge_ref: R2.2, R3.1, U3.3 (+)
/demod_out: C7.2, C8.2, R1.1, TP4.1, U6.6 (-IN_B), U6.7 (OUT_B)
/ina_out: R11.1, TP6.1, U4.6, U5.16 (R_{A}), U5.17 (R_{in}B)
/sens_out: J3.2, U2.3 (+)
/v_ac: R17.2, TP5.1, U8.10 (VOUT)
AGND: C1.1, C2.2, C3.2, C4.2, C5.2, C31.2, C32.2, C33.2, C34.2, C35.2, C36.1, C37.2, C38.2, C39.1, C40.2, D1.1 (K), J3.1, R3.2, R10.2, R16.2, U1.2 (AGND), U1.3 (REFIN-), U1.6 (CH1), U5.1 (R_{in}A), U5.10 (SEL_A), U5.14 (R_{B}), U8.9 (AGND)
DGND: C6.2, C9.2, C10.2, C12.2, C13.1, C14.1, C15.1, C16.1, C17.1, C20.1, C21.2, C22.1, C23.1, C24.1, C25.1, C26.2, C27.2, C28.2, C29.2, C30.2, C41.2, C42.2, C43.1, DS1.11 (VSS), IC1.7 (VSS/VSSA), J1.4 (GND), J1.5 (Shield), J1.6 (Shield), J2.3 (GND), J2.5 (GND), J2.9 (GND), SW1.1, U1.19 (DGND), U8.4 (DGND), U9.2 (GND), U10.14 (VSS), U11.1 (GND), USBLC1.2 (GND), USBLC2.2 (GND)
unnamed: C7.1, C8.1, R13.1, R14.1
unnamed: D1.2 (A), R23.2
unnamed: C19.2, DS1.8 (C1+)
unnamed: C19.1, DS1.9 (C1-)
unnamed: C18.1, DS1.7 (C2+)
unnamed: C18.2, DS1.6 (C2-)
unnamed: C13.2, DS1.1 (V0)
unnamed: C14.2, DS1.2 (V1)
unnamed: C15.2, DS1.3 (V2)
unnamed: C16.2, DS1.4 (V3)
unnamed: C17.2, DS1.5 (V4)
unnamed: C20.2, DS1.10 (VOUT)
unnamed: J2.4 (SWCLK), USBLC2.6 (I/O1)
unnamed: J2.2 (SWDIO), USBLC2.4 (I/O2)
unnamed: J3.3, R4.2
unnamed: R5.1, R6.2, U3.2 (-)
unnamed: R5.2, R7.2, U2.2 (-)
unnamed: R6.1, R9.2, U3.6
unnamed: R7.1, R8.1, U2.6
unnamed: R8.2, R10.1, U4.3 (+)
unnamed: R9.1, R11.2, U4.2 (-)
unnamed: R15.2, R16.1, U7.2 (-)
unnamed: R17.1, R18.2, U7.3 (+)
unnamed: R21.1, U1.17 (*IRQ/MDAT)
unnamed: U5.15 (R_{F}), U5.19 (CHB-), U5.20 (CHA-)
unnamed: R12.1, U5.12 (COMP), U5.13 (V_{OUT})
unnamed: C2.1, R12.2, U6.3 (+IN_A)
unnamed: C3.1, R14.2, U6.5 (+IN_B)
unnamed: R13.2, U6.1 (OUT_A), U6.2 (-IN_A)
unnamed: C24.2, U8.3 (CAP/2.5V)
unnamed: C25.2, U8.1 (COMP)
unnamed: C11.1, U11.6 (CAP+)
unnamed: C11.2, U11.3 (CAP-)

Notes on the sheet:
Wheatstone Quarter Bridge
Modified Howland Pump
USB-to-UART Converter
Anti-Aliasing Filter
MCU
+3V3 LDO Voltage Regulator
Function Generation
SWD Header
Digitization
Instrumentation Amplifier
Power Indicator
Charge Pump
USB-C Connector
LCD Screen
Synchronous Demodulator

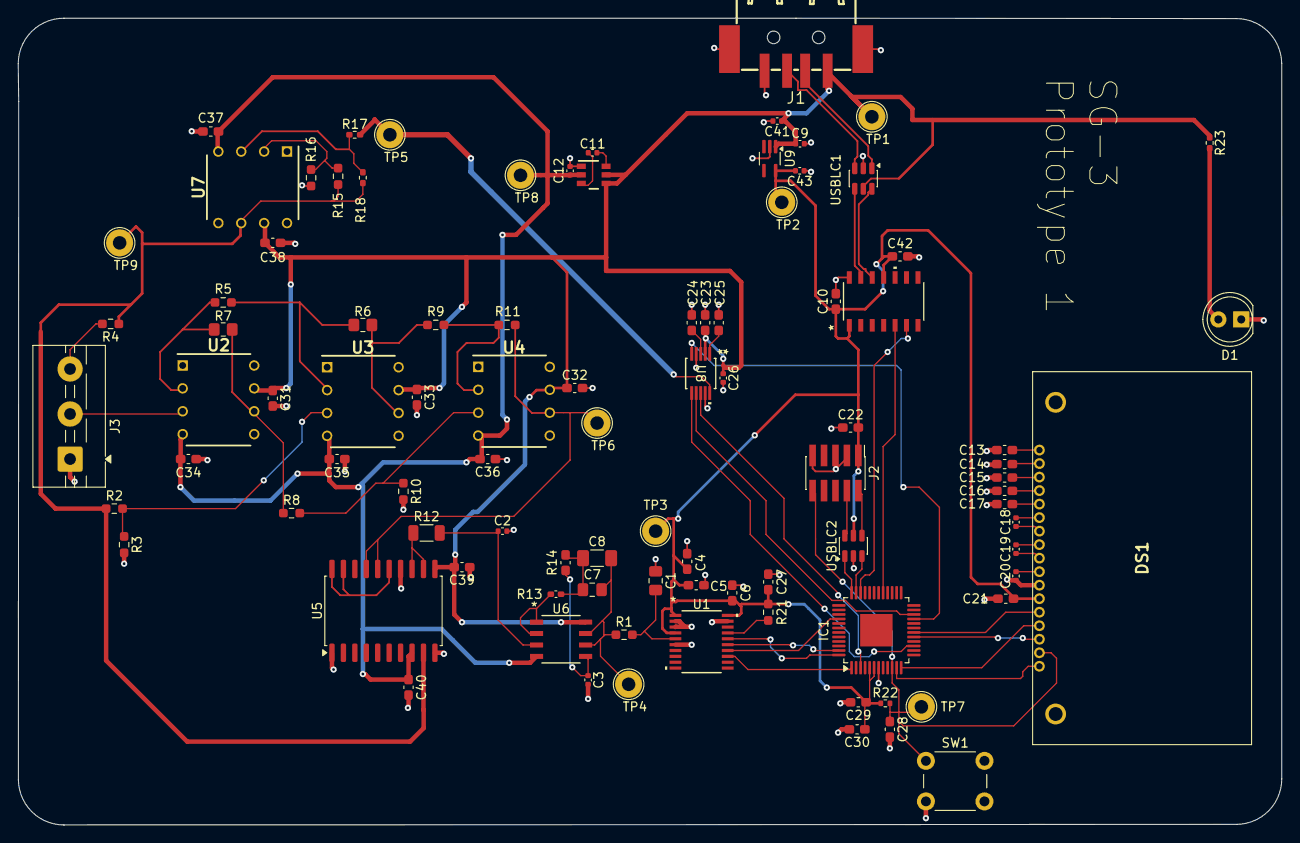
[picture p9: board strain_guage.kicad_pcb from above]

Board: 4 copper layers, 140.3 x 89.5 mm, 93 parts (0 on the bottom side), 64 nets.

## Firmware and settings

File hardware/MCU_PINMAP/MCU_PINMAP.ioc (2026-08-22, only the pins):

Mcu.UserName=STM32C091CBTx
PA0.Signal=GPIO_Output
PA1.Signal=SPI1_SCK
PA10.Signal=USART1_RX
PA13.Signal=DEBUG_SWDIO
PA14-BOOT0.Signal=DEBUG_SWCLK
PA3.Signal=GPIO_Output
PA4.Signal=SPI2_MOSI
PA5.Signal=GPIO_Output
PA6.Signal=SPI1_MISO
PA7.Signal=SPI1_MOSI
PA9.Signal=USART1_TX
PB10.Signal=SPI2_SCK
PB2.Signal=RCC_MCO_2
PB8.Signal=USART3_TX
PB9.Signal=USART3_RX
PC13.Signal=GPIO_Output
PC15-OSCX_OUT(PC15).Signal=GPIO_Output
PD2.Signal=USART3_CK

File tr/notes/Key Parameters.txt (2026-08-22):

Sensor Gauge C5K-06-S5145-350-33F:
 
- Has a nominal gauge factor of 2.10
- Has resistance of 350 ± 0.2% (ohms)
- Has a strain range of ±1.5%

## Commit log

2026-08-23 Upload Schematic
2026-08-27 PCB Revision + BOM Update
    Footprints for Op-Amps were corrected, package size for R22 was updated. PCB Layout and Tracing marginally modified
    [BOM-JLCPCB Assembly Order.xls, BOM.csv, bom.csv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]
2026-08-28 PCB Layout picture
2026-08-28 Rename PCB Layout.png to PCB_Layout.png
2026-08-29 Uploading 3D model of board
2026-09-02 Op-Amp footprints updated
    [BOM-JLCPCB Assembly Order.xls, bom.csv, positions.csv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]
2026-09-07 Small changes to improve manufacturability
    [bom.csv, positions.csv, strain_guage.kicad_pcb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]
